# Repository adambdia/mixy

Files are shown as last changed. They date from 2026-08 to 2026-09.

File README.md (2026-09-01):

# Mixy
 Custom peripheral to mix game and chat audio on the fly, meant to emulate the Steelseries chatmix dial.
 Tested with Python 3.14.7, PipeWire on Fedora.

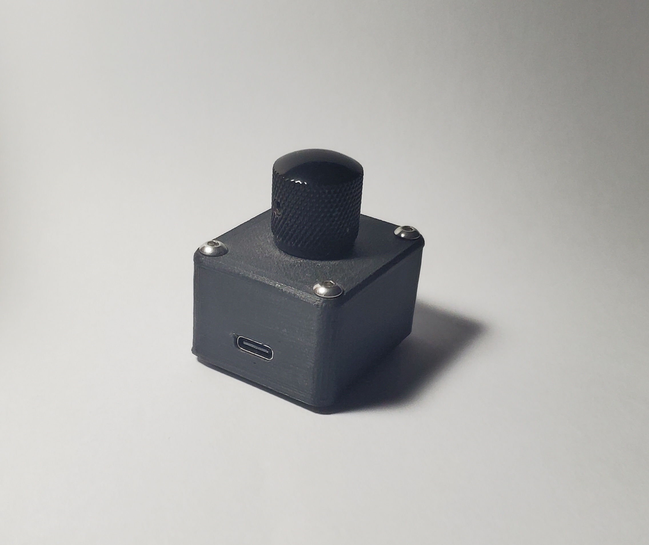
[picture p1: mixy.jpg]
Mixy Device


## Usage
Turn all the way to the left for desktop only, and all the way to the right for chat only. Center the dial to equalize both. You'll hear a pop noise when you've centered the dial for feedback.

## Build your own

### What you'll need
- A potentiometer, I used a generic 10k I had laying around
- A dial for your potentiometer, I got some nice metal ones on Aliexpress but you can 3D print one if you wish
- A USB-C microcontroller, I used a clone of the [Waveshare RP2040-zero ](https://www.waveshare.com/rp2040-zero.htm)
  - If not using a pi pico you'll need to modify the platformio.ini
- 4 M3x4mm threaded inserts
- 4 M3x5mm screws
  - I used hex button head screws because I think they look nice
- Some wire
- Hot glue

### Steps
- Print the `mixy-shell.stl` and `mixy-lid.stl` from the hardware folder
- Add the threaded inserts to the shell
- Solder up the potentiometer as a 3.3V voltage divider to pin 26
- Screw on the potentiometer to the lid with its nut
- Hotglue the board in place with the USB port flush with the shell
- Upload code to board from the firmware folder with platformio

## Setup Software
- Create a venv and install packages from `requirements.txt`
- Add yourself to the dialout group with `sudo usermod -aG dialout $USER`
- Create a mixy.service file in `/home/USER/.config/systemd/user` with the following contents
```
[Unit]
Description=Mixy Audio Dial Service
# Wait until PipeWire and the user audio session are fully loaded
After=pipewire.service pipewire-pulse.service wireplumber.service

[Service]
Type=simple
# Replace with the absolute path to your Python interpreter and script
ExecStart=/pathtovenv/bin/python3 /pathtomixy/host-software/main.py
Restart=always
RestartSec=5

[Install]
WantedBy=default.target
```
- Enable the service and start the service with the following commands
```
systemctl --user daemon-reload
systemctl --user enable mixy.service
systemctl --user start mixy.service
```
- Find your speakers/headphones with `pactl list sinks short | grep -v mixy` and replace the one in `99-mixy-sinks.conf` at `target.object = "YOURDEVICE"`
- Copy or symlink the conf file with `ln -sf /home/adam/Documents/mixy/host-software/99-mixy-sinks.conf ~/.config/pipewire/pipewire.conf.d/99-mixy-sinks.conf` then log out and back in
- Use something like [pavucontrol](https://flathub.org/en/apps/org.pulseaudio.pavucontrol) to make sure all the audio devices are pointing to the right places
- Done!

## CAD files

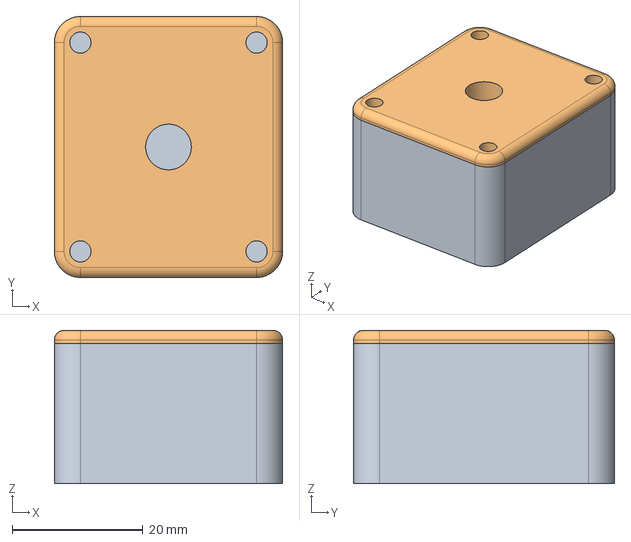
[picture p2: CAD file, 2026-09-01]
hardware/mixy-shell.FCStd
35.0 x 40.0 x 23.5 mm
Lid

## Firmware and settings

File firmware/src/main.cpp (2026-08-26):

#include <Adafruit_TinyUSB.h>
#include <Arduino.h>
#include <cstdint>

const int POT = 26;
const uint32_t LOOP_PERIOD = 50; // 100 ms
uint32_t last_loop = 0;

void setup()
{
    USBDevice.setManufacturerDescriptor("Adam Dia");
    USBDevice.setProductDescriptor("mixy Audio Dial");
    Serial.begin(9600);
    analogReadResolution(12);
}

void loop()
{
    if (millis() - last_loop > LOOP_PERIOD)
    {
        int reading = analogRead(POT);
        int level = map(reading, 0, 4095, 0, 100);
        char buf[8] = {0};
        itoa(level, buf, 10);
        strcat(buf, "\n");
        Serial.print(buf);
        last_loop = millis();
    }
}

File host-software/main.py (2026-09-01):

#!/usr/bin/env python3

import pulsectl
import serial
import mixy
import time

ser = mixy.open_device()
pulse, desktop_sink, chat_sink = mixy.pulse_init()
old_desktop_vol = -1
old_chat_vol = -1

print("Starting loop.", flush=True)
while True:
    try:
        raw_data = ser.readline()
        data_str = raw_data.decode(errors="ignore").strip()
        dial_val = int(data_str)
        desktop_vol, chat_vol = mixy.volume_from_dial(dial_val)
        # avoid constantly setting the volume
        if desktop_vol != old_desktop_vol or chat_vol != old_chat_vol:
            print(f"Setting volume: {desktop_vol}, {chat_vol}", flush=True)
            mixy.set_volume(pulse, desktop_sink, chat_sink, desktop_vol, chat_vol)
            old_desktop_vol = desktop_vol
            old_chat_vol = chat_vol

        # sound feedback
        if mixy.dial_in_deadzone(dial_val):
            if mixy.in_deadzone == False:
                mixy.play_pop()
                mixy.in_deadzone = True
        else:
            mixy.in_deadzone = False

    except KeyboardInterrupt:
        break
    except serial.serialutil.SerialException:
        print("Lost connection to Mixy, reconnecting...", flush=True)
        try:
            ser.close()
        except Exception:
            pass
        ser = mixy.open_device()
    except (
        pulsectl.PulseError,
        pulsectl.PulseOperationInvalid,
        pulsectl.PulseDisconnected,
    ) as e:
        print(f"PipeWire connection reset ({e}), reconnecting...", flush=True)
        try:
            pulse.close()
        except Exception:
            pass
        time.sleep(2)
        pulse, desktop_sink, chat_sink = mixy.pulse_init()
    except Exception as e:
        print(f"Unexpected error: {e}", flush=True)
        time.sleep(1)

print("Terminating.", flush=True)
try:
    ser.close()
    pulse.close()
except Exception:
    pass

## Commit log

2025-12-19 CAD for enclosure
    [mixy-shell.FCStd]
2025-12-21 shell v2
    [mixy-shell.FCStd]
2025-12-22 changed height of usbc hole and added holes for extra screw length so they dont bottom out
    [mixy-shell.FCStd]
2025-12-27 final changes to shell for now, adjusted inserts and usbc height
    [mixy-shell.FCStd]
2026-05-07 using a pi pico now
2026-08-27 changed name of audio devices in pipewire conf
2026-08-31 searching for sinks is persistent, runs correctly on login
    [main.py, mixy.py]
2026-09-01 cleaned up hardware folder
    [mixy-shell.FCStd]
